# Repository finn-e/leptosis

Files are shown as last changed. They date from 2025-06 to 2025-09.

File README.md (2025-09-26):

# Leptosis - Ultra Flat PG1316 Split Keyboard



"Leptos" stands for "flat" in greek, added with the suffix is, it forms the word "Leptosis", signifying the most flat. This represents my long lasting desire for an real flat keyboard that is portable and light. The name is also quite similar to the latin word "levitatio", signifying levitation and thus light. (I'm bad at naming things lol)

## What is this?

Leptosis is an ultra flat split bluetooth keyboard. It's thickness will be ~7.5mm, and employs the compact miryoku layout. Using an onboard nrf module, it achieves an ultra long battery life.

| Left | Right |
| ---- | ----- |
|  |  |

## Features
- Ultra long battery life (~4 months for central and 1 year for peripheral)
- Ultra thin (7.5mm)
- Compact (13.2x9.2cm)
- Custom battery management and optimization
- Embedded nrf52 mcu
- ZMK bluetooth



## Fabrication

You can either use PCBA to fabricate the PCB, or reflow it yourself. I highly discurrage you to reflow the yourself if you haven't reflowed a aQFN package before - it's a nightmare to get right.

The PCB files are in the `hardware` directory, you need to buy one pcb for the right and the left. There is also a V-Cut panneled version in `hardware/panel`. It uses JLCPCB's 1.2mm JLC04121H-7628 stackup. Other stackups would require re-tuning of the USB data lines and antenna feed trace.

The case is in the `CAD` directory. Print out all `.step` files.

The software is in the `firmware`. Leptosis uses ZMK, allowing ultra long battery life.

After fabrication, solder on some jumpers onto the 4 test pads, and connect it to a JTAG connector (I'm using the ST-LINK). Download the bootloader from the newest action [here](https://github.com/cheyao/Adafruit_nRF52_Bootloader/actions) and unzip it.

For stlink, install openocd and run the following commands:

```zsh
openocd -f /usr/share/openocd/scripts/interface/stlink.cfg -f /usr/share/openocd/scripts/target/nrf52.cfg -c 'program <path_to_bootloader>.hex verify reset; shutdown;'
```

For other JTAG connectors, please refer to your own documentation.

Now plug in a USB-C cable, and you should see a mass storage device called `LEPTOSIS`.

Download the ZMK config from this repo: https://github.com/cheyao/zmk-config/actions, drag the utf file to the mass storage device and you are done!

## Misc

Liked this project? Drop a star and check out my [other Icepi Zero project](https://www.crowdsupply.com/icy-electronics/icepi-zero/)!

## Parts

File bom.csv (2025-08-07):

Name | Qty | Cost | Link
PG1316 switches | 60 | 55$ | https://holykeebs.com/products/kailh-pg1316s-butterfly-switch-10-pack
Keycaps | 62 | 29$ | https://holykeebs.com/products/kailh-pg1316s-keycaps?variant=49205120401698
PCB + Stencil | 2 | 46.79$
Batteries | 2 | 14.71$ | https://fr.aliexpress.com/item/1005009330714076.html
LCSC Components | 1 | 30$

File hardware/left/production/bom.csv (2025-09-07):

Designator | Footprint | Quantity | Value | LCSC Part #
C1, C2, C3, C4 | 0402 | 4 | 15pF | C1548
C10 | 0402 | 1 | 820pF | C107031
C11, C17 | 0603 | 2 | 1uF | C15849
C12 | 0402 | 1 | 47nF | C272875
C13, C14, C15, C16, C21, C22 | 0603 | 6 | 4.7uF | C19666
C18, C19, C20, C23, C8 | 0402 | 5 | 100nF | C1525
C5 | 0402 | 1 | 0.8pF | C41361068
C6 | 0402 | 1 | 0.5pF | C76912
C9 | 0402 | 1 | 100pF | C1546
D1, D10, D11, D13, D14, D15, D16, D17, D2, D21, D22, D23, D3, D4, D5, D7, D8, D9 | D_SOD-123 | 18 | 1N4148W | C81598
D31 | 0603 | 1 | LED | C2290
J1 | USB_C_Receptacle_HRO_TYPE-C-31-M-14 | 1 | USB_C_Receptacle_USB2.0_14P | C223907
L1 | 0402 | 1 | 4.7nH | C86065
L2, L4 | 0603 | 2 | 10uH | C86083
L3 | 0402 | 1 | 15nH | C86059
Q2 | SOT-23 | 1 | 2N7002 | C8545
R1, R15, R16, R2 | 0402 | 4 | 5.1k | C25905
R10, R3, R6, R8 | 0402 | 4 | 10k | C25744
R4 | 0402 | 1 | 3.9k | C131467
R5, R9 | 0402 | 2 | 1.5k | C25867
R7 | 0402 | 1 | 100 | C25076
SW10, SW11, SW12, SW14, SW15, SW16, SW17, SW18, SW2, SW22, SW23, SW24, SW3, SW4, SW5, SW6, SW8, SW9 | SW_PG1316S | 18 | SW_Push
SW31 | Switch_Sink_MINI_MSK12CO2 | 1 | SW_SPDT | C2681570
U1 | Nordic_AQFN-73-1EP_7x7mm_P0.5mm | 1 | nRF52840 | C190794
U2 | VQFN-16-1EP_3x3mm_P0.5mm_EP1.6x1.6mm | 1 | BQ24075RGT | C15464
U3 | WLP-8_1.67x0.93_P0.4 | 1 | MAX17048X | C7497002
Y1 | Crystal_SMD_2016-4Pin_2.0x1.6mm | 1 | 32MHz 12pF | C2682773
Y2 | Crystal_SMD_3215-2Pin_3.2x1.5mm | 1 | 32.768kHz 12.5pF | C5213671

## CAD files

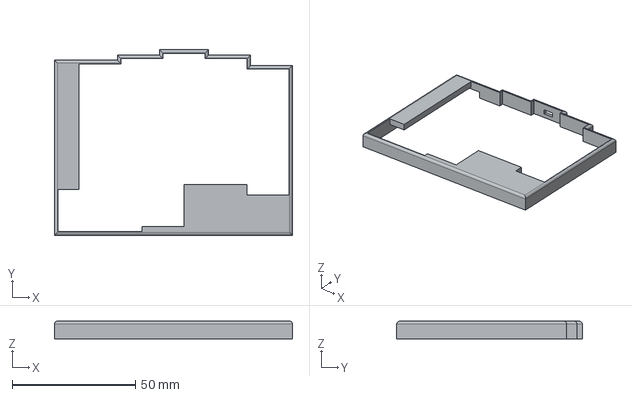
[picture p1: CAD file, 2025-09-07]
CAD/left-top.step
96.5 x 75.2 x 7.20 mm

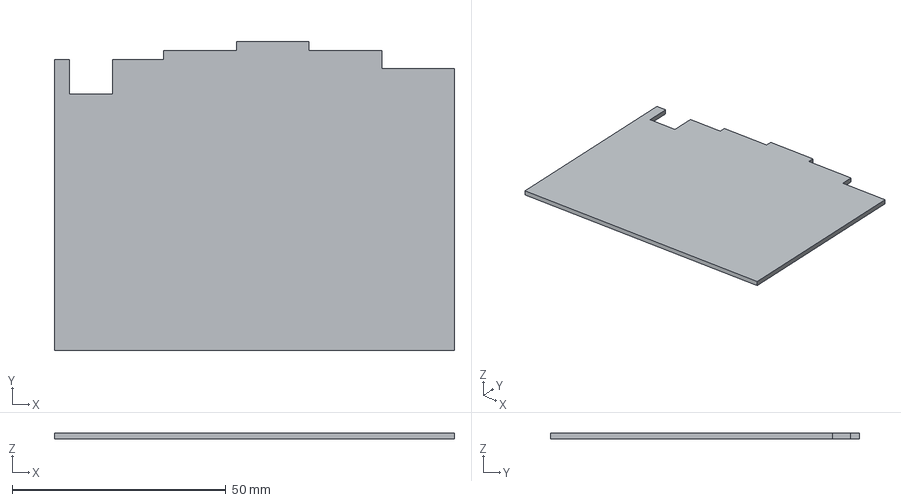
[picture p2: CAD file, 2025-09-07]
CAD/left-bottom.step
93.5 x 72.2 x 1.50 mm

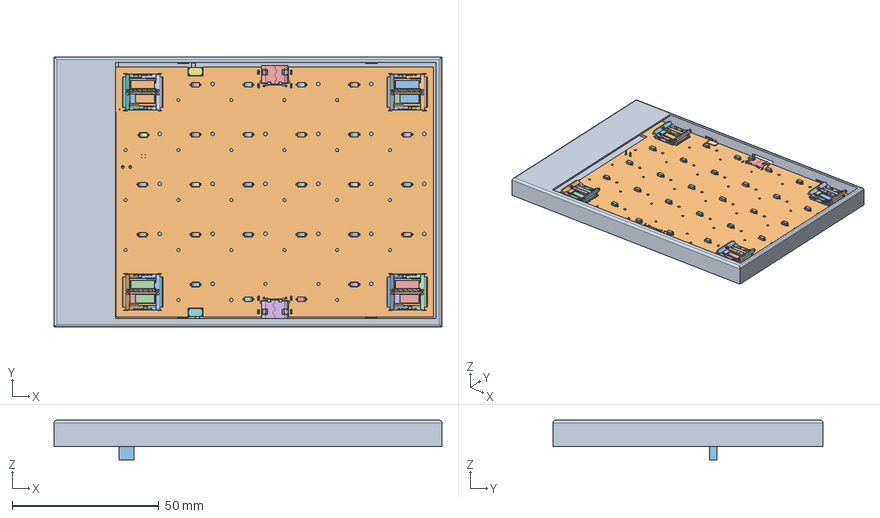
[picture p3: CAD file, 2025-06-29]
CAD/case.FCStd
132.0 x 92.0 x 13.6 mm
D_SOD-123
D_SOD-124
D_SOD-125
D_SOD-126
D_SOD-127
D_SOD-128
D_SOD-129
D_SOD-130
D_SOD-131
D_SOD-132
D_SOD-133
D_SOD-134
D_SOD-135
D_SOD-136
D_SOD-137
D_SOD-138
D_SOD-139
D_SOD-140
D_SOD-141
D_SOD-142
D_SOD-143
D_SOD-144
D_SOD-145
D_SOD-146
D_SOD-147
D_SOD-148
D_SOD-149
D_SOD-150
D_SOD-151
D_SOD-152
C_0603_1608Metric
C_0402_1005Metric
C_0603_1608Metric001
C_0402_1005Metric001
PinSocket_1x02_P2.54mm_Vertical
Nordic_AQFN-73-1EP_7x7mm_P0.5mm
R_0402_1005Metric
L_0402_1005Metric
C_0402_1005Metric002
R_0402_1005Metric001
R_0402_1005Metric002
C_0603_1608Metric002
LED_0603_1608Metric
Crystal_SMD_3215-2Pin_3.2x1.5mm
C_0402_1005Metric003
C_0603_1608Metric003
R_0402_1005Metric003
L_0603_1608Metric
L_0603_1608Metric001
R_0402_1005Metric004
C_0402_1005Metric004
C_0402_1005Metric005
C_0402_1005Metric006
L_0402_1005Metric001
C_0402_1005Metric007
R_0402_1005Metric005
C_0402_1005Metric008
Shroud
Plastic Body & Connector
R_0402_1005Metric006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

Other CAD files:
CAD/right-top.step
CAD/right-bottom.step

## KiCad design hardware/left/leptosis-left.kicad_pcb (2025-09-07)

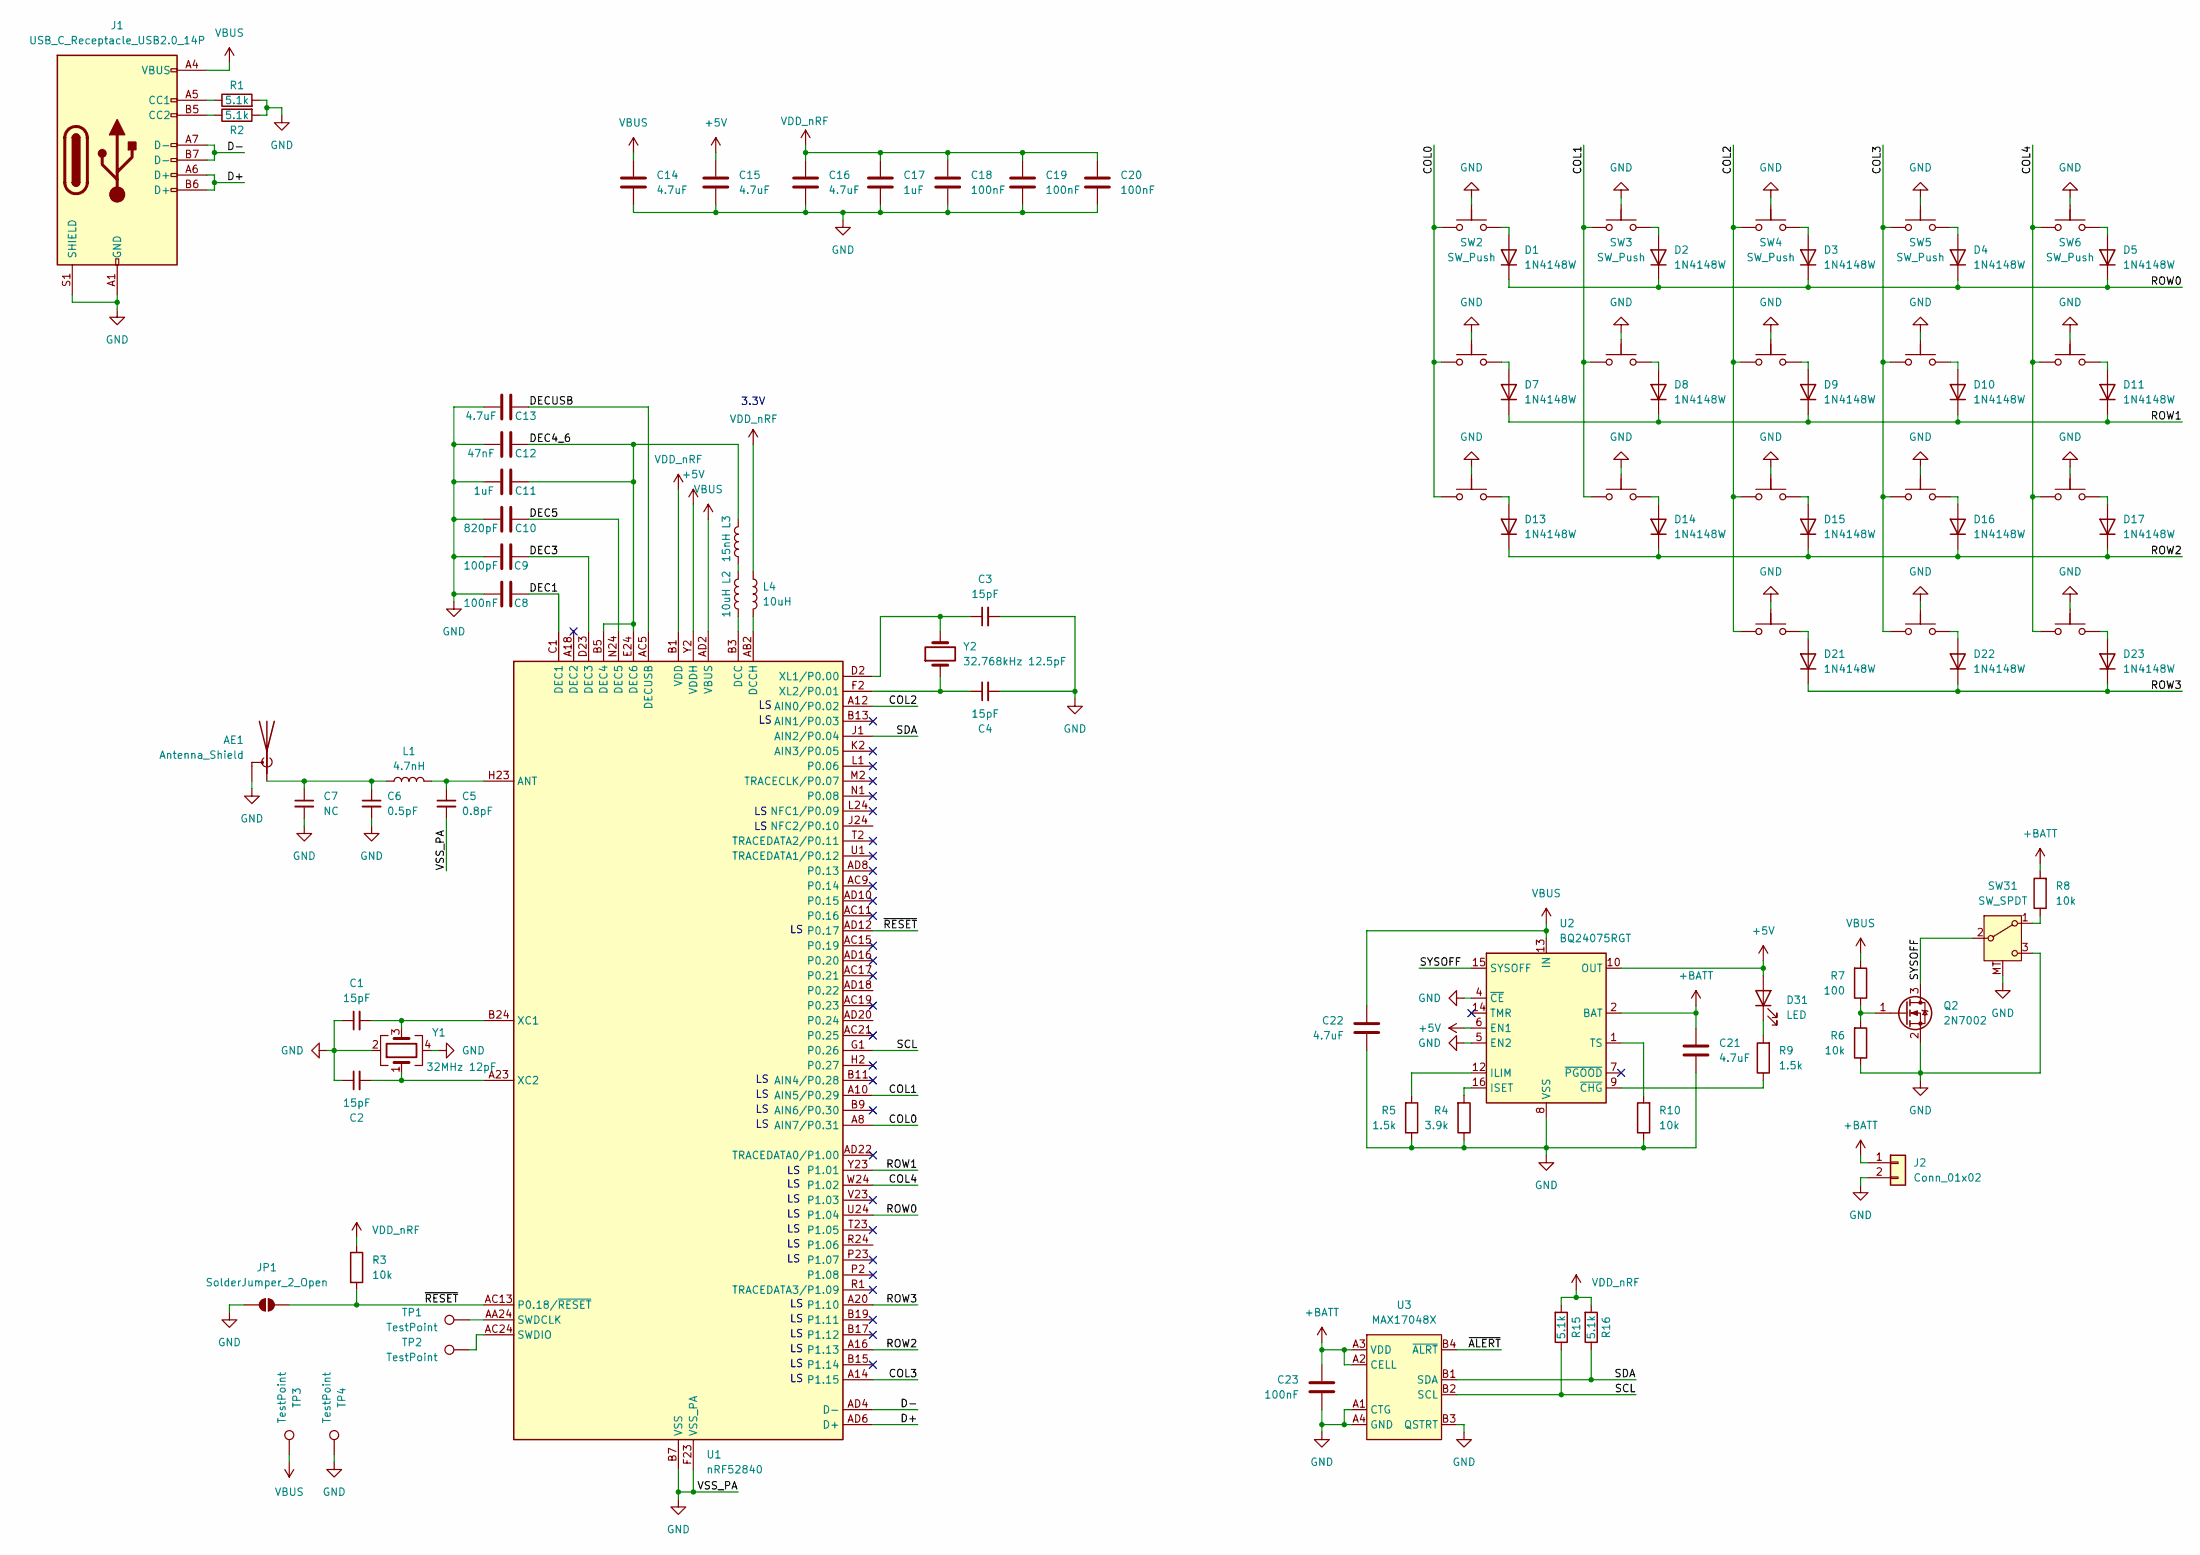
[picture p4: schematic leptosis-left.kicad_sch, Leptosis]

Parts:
AE1: Antenna_Shield; Texas_SWRA117D_2.4GHz_Left
C1, C2, C3, C4: 15pF; C_0402_1005Metric; LCSC Part # C1548
C5: 0.8pF; C_0402_1005Metric; LCSC Part # C41361068
C6: 0.5pF; C_0402_1005Metric; LCSC Part # C76912
C7: NC; C_0402_1005Metric
C8, C18, C19, C20, C23: 100nF; C_0402_1005Metric; LCSC Part # C1525
C9: 100pF; C_0402_1005Metric; LCSC Part # C1546
C10: 820pF; C_0402_1005Metric; LCSC Part # C107031
C11, C17: 1uF; C_0603_1608Metric; LCSC Part # C15849
C12: 47nF; C_0402_1005Metric; LCSC Part # C272875
C13, C14, C15, C16, C21, C22: 4.7uF; C_0603_1608Metric; LCSC Part # C19666
D1, D2, D3, D4, D5, D7, D8, D9, D10, D11, D13, D14, D15, D16, D17, D21, D22, D23: 1N4148W; D_SOD-123; LCSC Part # C81598
D31: LED; LED_0603_1608Metric_Pad1.05x0.95mm_HandSolder; LCSC Part # C2290
J1: USB_C_Receptacle_USB2.0_14P; USB_C_Receptacle_HRO_TYPE-C-31-M-14; LCSC Part # C223907
J2: Conn_01x02; PinSocket_1x02_P2.54mm_Vertical
JP1: SolderJumper_2_Open; SolderJumper-2_P1.3mm_Open_RoundedPad1.0x1.5mm
L1: 4.7nH; L_0402_1005Metric; LCSC Part # C86065
L2, L4: 10uH; L_0603_1608Metric; LCSC Part # C86083
L3: 15nH; L_0402_1005Metric; LCSC Part # C86059
Q2: 2N7002; SOT-23; LCSC Part # C8545
R1, R2, R15, R16: 5.1k; R_0402_1005Metric_Pad0.72x0.64mm_HandSolder; LCSC Part # C25905
R3, R6, R8, R10: 10k; R_0402_1005Metric_Pad0.72x0.64mm_HandSolder; LCSC Part # C25744
R4: 3.9k; R_0402_1005Metric_Pad0.72x0.64mm_HandSolder; LCSC Part # C131467
R5, R9: 1.5k; R_0402_1005Metric_Pad0.72x0.64mm_HandSolder; LCSC Part # C25867
R7: 100; R_0402_1005Metric_Pad0.72x0.64mm_HandSolder; LCSC Part # C25076
SW2, SW3, SW4, SW5, SW6, SW8, SW9, SW10, SW11, SW12, SW14, SW15, SW16, SW17, SW18, SW22, SW23, SW24: SW_Push; SW_PG1316S
SW31: SW_SPDT; Switch_Sink_MINI_MSK12CO2; LCSC Part # C2681570
TP1, TP2, TP3, TP4: TestPoint; TestPoint_Pad_D1.5mm
U1: nRF52840; Nordic_AQFN-73-1EP_7x7mm_P0.5mm; LCSC Part # C190794
U2: BQ24075RGT; VQFN-16-1EP_3x3mm_P0.5mm_EP1.6x1.6mm; LCSC Part # C15464
U3: MAX17048X; WLP-8_1.67x0.93_P0.4; LCSC Part # C7497002
Y1: 32MHz 12pF; Crystal_SMD_2016-4Pin_2.0x1.6mm; LCSC Part # C2682773
Y2: 32.768kHz 12.5pF; Crystal_SMD_3215-2Pin_3.2x1.5mm; LCSC Part # C5213671

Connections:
+5V: C15.1, D31.2 (A), U1.Y2 (VDDH), U2.6 (EN1), U2.10 (OUT), U2.11 (OUT)
+BATT: C21.1, C23.1, J2.1, R8.2, U2.2 (BAT), U2.3 (BAT), U3.A2 (CELL), U3.A3 (VDD)
/COL0: SW2.1, SW8.1, SW14.1, U1.A8 (AIN7/P0.31)
/COL1: SW3.1, SW9.1, SW15.1, U1.A10 (AIN5/P0.29)
/COL2: SW4.1, SW10.1, SW16.1, SW22.1, U1.A12 (AIN0/P0.02)
/COL3: SW5.1, SW11.1, SW17.1, SW23.1, U1.A14 (P1.15)
/COL4: SW6.1, SW12.1, SW18.1, SW24.1, U1.W24 (P1.02)
/D+: J1.A6 (D+), J1.B6 (D+), U1.AD6 (D+)
/D-: J1.A7 (D-), J1.B7 (D-), U1.AD4 (D-)
/DEC1: C8.2, U1.C1 (DEC1)
/DEC3: C9.2, U1.D23 (DEC3)
/DEC4_6: C11.2, C12.2, L3.2, U1.B5 (DEC4), U1.E24 (DEC6)
/DEC5: C10.2, U1.N24 (DEC5)
/DECUSB: C13.2, U1.AC5 (DECUSB)
/ROW0: D1.1 (K), D2.1 (K), D3.1 (K), D4.1 (K), D5.1 (K), U1.U24 (P1.04)
/ROW1: D7.1 (K), D8.1 (K), D9.1 (K), D10.1 (K), D11.1 (K), U1.Y23 (P1.01)
/ROW2: D13.1 (K), D14.1 (K), D15.1 (K), D16.1 (K), D17.1 (K), U1.A16 (P1.13)
/ROW3: D21.1 (K), D22.1 (K), D23.1 (K), U1.A20 (P1.10)
/SCL: R15.1, U1.G1 (P0.26), U3.B2 (SCL)
/SDA: R16.1, U1.J1 (AIN2/P0.04), U3.B1 (SDA)
/SYSOFF: Q2.3 (D), SW31.2 (B), U2.15 (SYSOFF)
/~ALERT: U3.B4 (~ALRT)
/~RESET: JP1.2 (B), R3.2, U1.AC13 (P0.18/~RESET), U1.AD12 (P0.17)
GND: AE1.2 (Shield), C1.1, C2.1, C3.2, C4.2, C5.2, C6.2, C7.2, C8.1, C9.1, C10.1, C11.1, C12.1, C13.1, C14.2, C15.2, C16.2, C17.2, C18.2, C19.2, C20.2, C21.2, C22.2, C23.2, J1.A1 (GND), J1.A12 (GND), J1.B1 (GND), J1.B12 (GND), J1.S1 (SHIELD), J2.2, JP1.1 (A), Q2.2 (S), R1.2, R2.2, R4.1, R5.1, R6.1, R10.1, SW2.MP, SW3.MP, SW4.MP, SW5.MP, SW6.MP, SW8.MP, SW9.MP, SW10.MP, SW11.MP, SW12.MP, SW14.MP, SW15.MP, SW16.MP, SW17.MP, SW18.MP, SW22.MP, SW23.MP, SW24.MP, SW31.3 (C), SW31.MT, TP4.1, U1.B7 (VSS), U1.EP (VSS), U1.F23 (VSS_PA), U2.4 (~CE), U2.5 (EN2), U2.8 (VSS), U2.17 (VSS), U3.A1 (CTG), U3.A4 (GND), U3.B3 (QSTRT), Y1.2, Y1.4
unnamed: AE1.1 (A), C6.1, C7.1, L1.1
unnamed: D1.2 (A), SW2.2
unnamed: D2.2 (A), SW3.2
unnamed: D3.2 (A), SW4.2
unnamed: D4.2 (A), SW5.2
unnamed: D5.2 (A), SW6.2
unnamed: D7.2 (A), SW8.2
unnamed: D8.2 (A), SW9.2
unnamed: D9.2 (A), SW10.2
unnamed: D10.2 (A), SW11.2
unnamed: D11.2 (A), SW12.2
unnamed: D13.2 (A), SW14.2
unnamed: D14.2 (A), SW15.2
unnamed: D15.2 (A), SW16.2
unnamed: D16.2 (A), SW17.2
unnamed: D17.2 (A), SW18.2
unnamed: D21.2 (A), SW22.2
unnamed: D22.2 (A), SW23.2
unnamed: D23.2 (A), SW24.2
unnamed: D31.1 (K), R9.2
unnamed: J1.A5 (CC1), R1.1
unnamed: J1.B5 (CC2), R2.1
unnamed: L2.2, L3.1
unnamed: Q2.1 (G), R6.2, R7.1
unnamed: R8.1, SW31.1 (A)
unnamed: C5.1, L1.2, U1.H23 (ANT)
unnamed: L2.1, U1.B3 (DCC)
unnamed: L4.1, U1.AB2 (DCCH)
unnamed: TP1.1, U1.AA24 (SWDCLK)
unnamed: TP2.1, U1.AC24 (SWDIO)
unnamed: C1.2, U1.B24 (XC1), Y1.3
unnamed: C2.2, U1.A23 (XC2), Y1.1
unnamed: C3.1, U1.D2 (XL1/P0.00), Y2.2
unnamed: C4.1, U1.F2 (XL2/P0.01), Y2.1
unnamed: R5.2, U2.12 (ILIM)
unnamed: R4.2, U2.16 (ISET)
unnamed: R10.2, U2.1 (TS)
unnamed: R9.1, U2.9 (~CHG)
VBUS: C14.1, C22.1, J1.A4 (VBUS), J1.A9 (VBUS), J1.B4 (VBUS), J1.B9 (VBUS), R7.2, TP3.1, U1.AD2 (VBUS), U2.13 (IN)
VDD_nRF: C16.1, C17.1, C18.1, C19.1, C20.1, L4.2, R3.1, R15.2, R16.2, U1.A22 (VDD), U1.AD14 (VDD), U1.AD23 (VDD), U1.B1 (VDD), U1.W1 (VDD)

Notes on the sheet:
3.3V

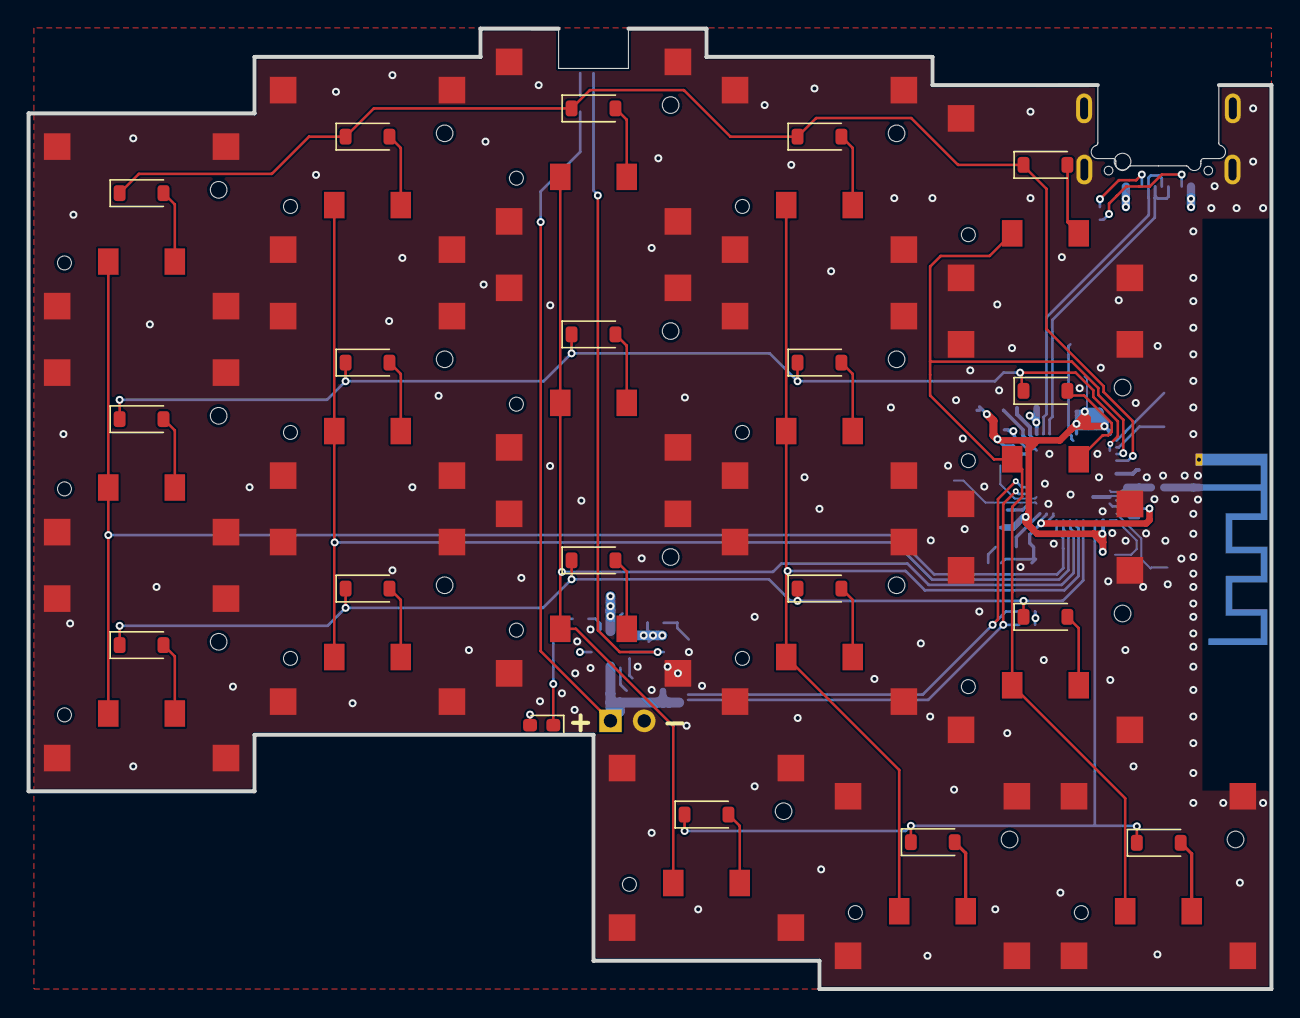
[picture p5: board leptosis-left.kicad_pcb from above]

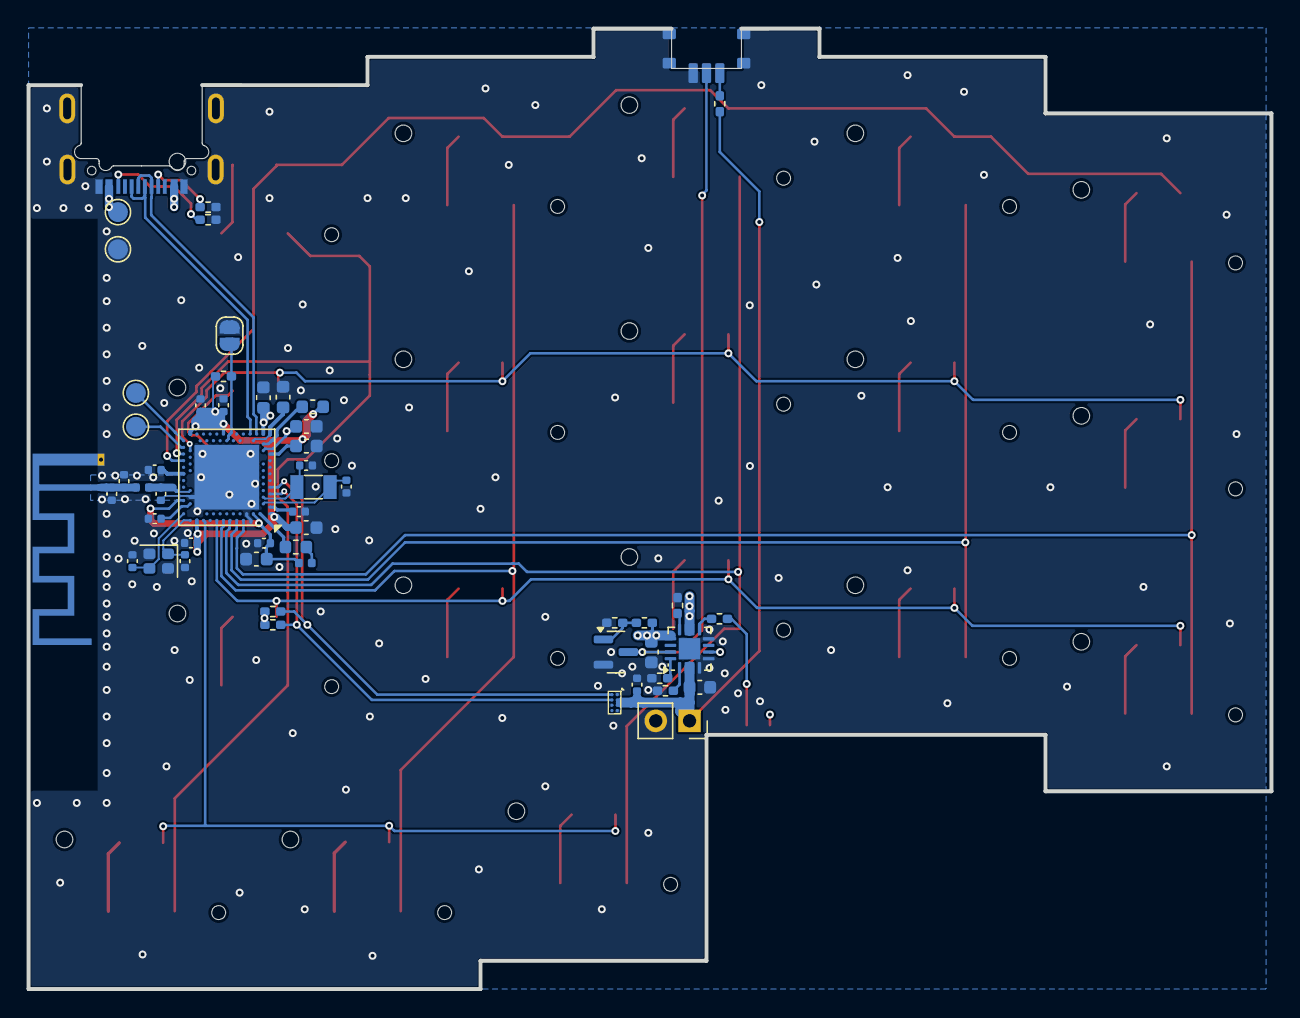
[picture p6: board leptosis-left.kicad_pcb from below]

Board: 4 copper layers, 93.5 x 72.3 mm, 91 parts (54 on the bottom side), 63 nets.

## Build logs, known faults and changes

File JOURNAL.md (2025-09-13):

---
Title: "Leptosis"
Author: "Cyao"
Description: "Leptosis"
Created On: "25/6/2005"
---

Time spent: 35h

## 25/06/2005

Made the basic pg1316 layout!



- 1.5h

-----------

Designed the nrf module!



- 1.5h

-----------

Starting to layout the nrf,,,



- 1h

-----------

## 26/06/2005

The nrf chip is done laying out!



- 2h

-----------

And also layed out the BMS :3



- 2h

-----------

Routed all of my switch routes to low speed pins.
 


- 1.5h

-----------

## 27/06/2005

Added the on/off switches and did misc changes!



- 1.5h

-----------

## 28/06/2005

Keeb got changed to 2 layers to reduce cost.



- 2h

-----------

## 29/06/2025

Made the case, improved pcb and wrote out readme :D



- 2h

NOTE: https://github.com/adafruit/Adafruit_nRF52_Bootloader

-----------

This is the end of v1, I am not happy with this



- 1h

-----------

## 02,03,04/07/2025

Finished with the keys



- 4.5h :O

-----------

## 04/07/2025

Now the main layout is done :D



- 3.5h

-----------

## 05-06/07/2025

And I've also finished the right side!!!



- 3h

-----------

The case is also finished!



- 1h

-----------

Aaand I finally shipped everything :yay:

- 1h

--------

Tried PCBA myself, failed misserably. But made custon bootloader firmware! (https://github.com/cheyao/Adafruit_nRF52_Bootloader/)



- 6h

-----------

Finally got PCBAed PCBs, and soldered on the switches and misc stuff myself



- 4h

----------------

Made the custom zmk firmware https://github.com/cheyao/zmk-config/, the zmk docs are a bit long lmao



Printed the case and voila!

- 5h

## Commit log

2025-06-26 Finish most of schem
    [bom.csv, designators.csv, positions.csv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]
2025-06-28 2 Layers
    [bom.csv, designators.csv, positions.csv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]
2025-07-06 Split keeb!
    [bom.csv, designators.csv, left.step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]
2025-09-07 Add permissive solderpad license
